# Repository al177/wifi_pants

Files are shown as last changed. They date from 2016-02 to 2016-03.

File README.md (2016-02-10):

# wifi_pants
The dawn of the IoP era

Released under the [Creative Commons Share Alike (CC-BY-SA) License](https://creativecommons.org/licenses/by-sa/4.0/).  Share it, change it, make money on it, teach it to the children as a cautionary tale.  Just make your changes public and give credit to all contributors to this project.

Attributions:

Andrew Litt (dev)

Jerry Dunmire (for the esp8266 Kicad library https://github.com/jdunmire/kicad-ESP8266)

Mike Cousins (for the nice mcous discrete footprints https://github.com/mcous/kicad-lib)

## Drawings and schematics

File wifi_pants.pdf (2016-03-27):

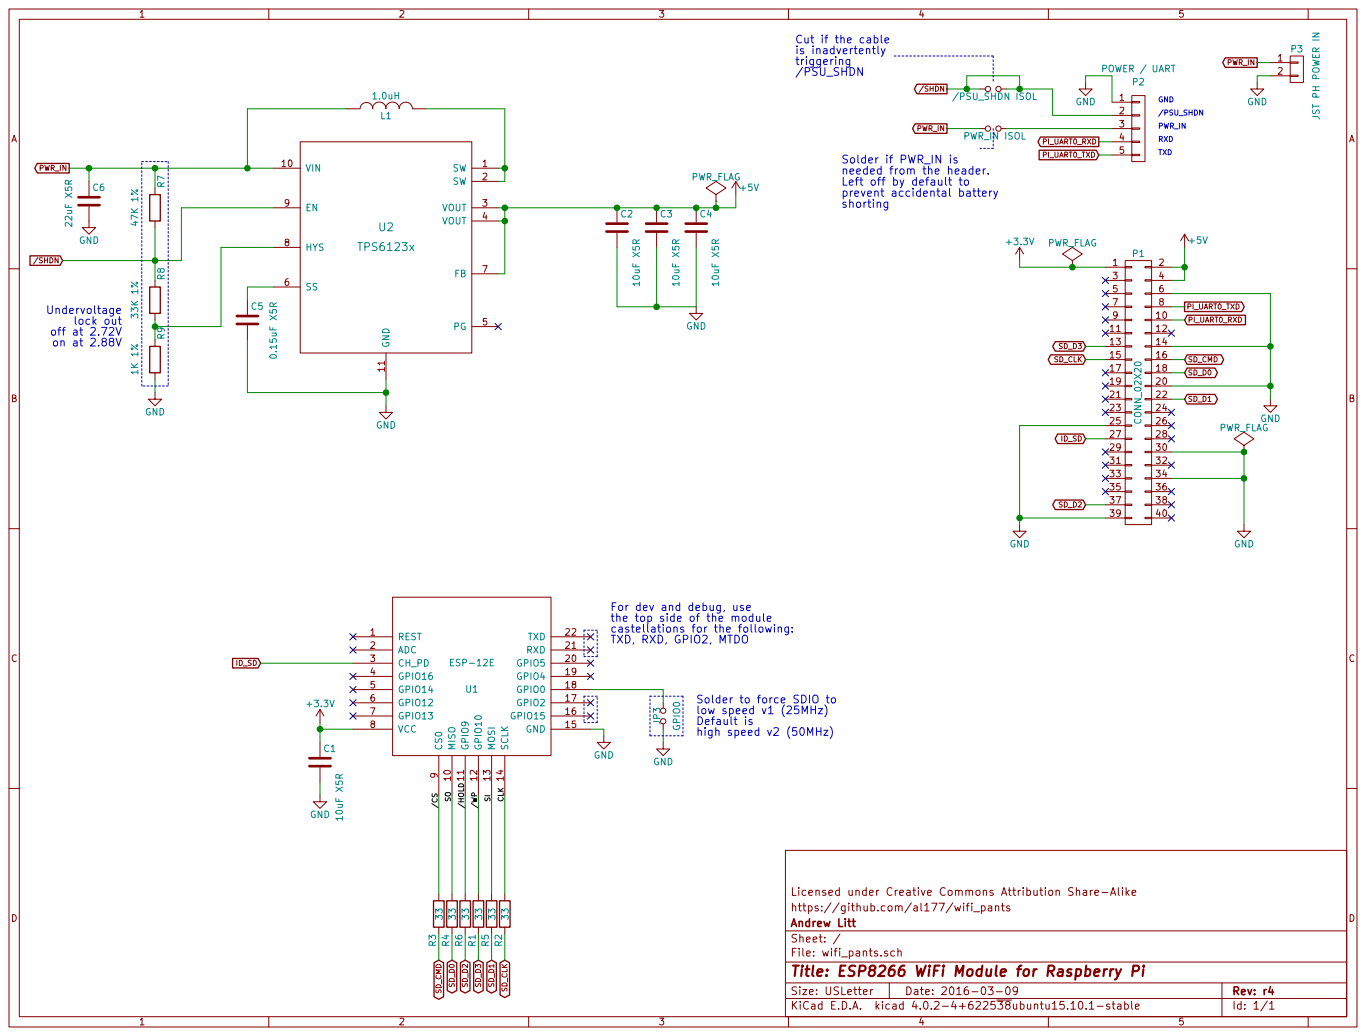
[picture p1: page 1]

/PSU_SHDN ISOL Cut if the cable
is inadvertently
triggering

2 P3 JST PH POWER IN PWR_INGND

RXD For dev and debug, use

GND Undervoltage
lock out off at 2.72V

the top side of the module
castellations for the following:
TXD, RXD, GPIO2, MTDO

9 MISO 10 GPIO5 20 GPIO9 11 RXD 21 GPIO10 12 TXD 22 MOSI 13 SCLK 14 GND 15 GPIO15 16 GPIO2 17 GPIO0 18 GPIO4 19 U1 ESP-12E

Solder to force SDIO to

File: wifi_pants.sch Sheet: / Andrew Litt https://github.com/al177/wifi_pants Licensed under Creative Commons Attribution Share-Alike

Id: 1/1 Title: ESP8266 WiFi Module for Raspberry Pi

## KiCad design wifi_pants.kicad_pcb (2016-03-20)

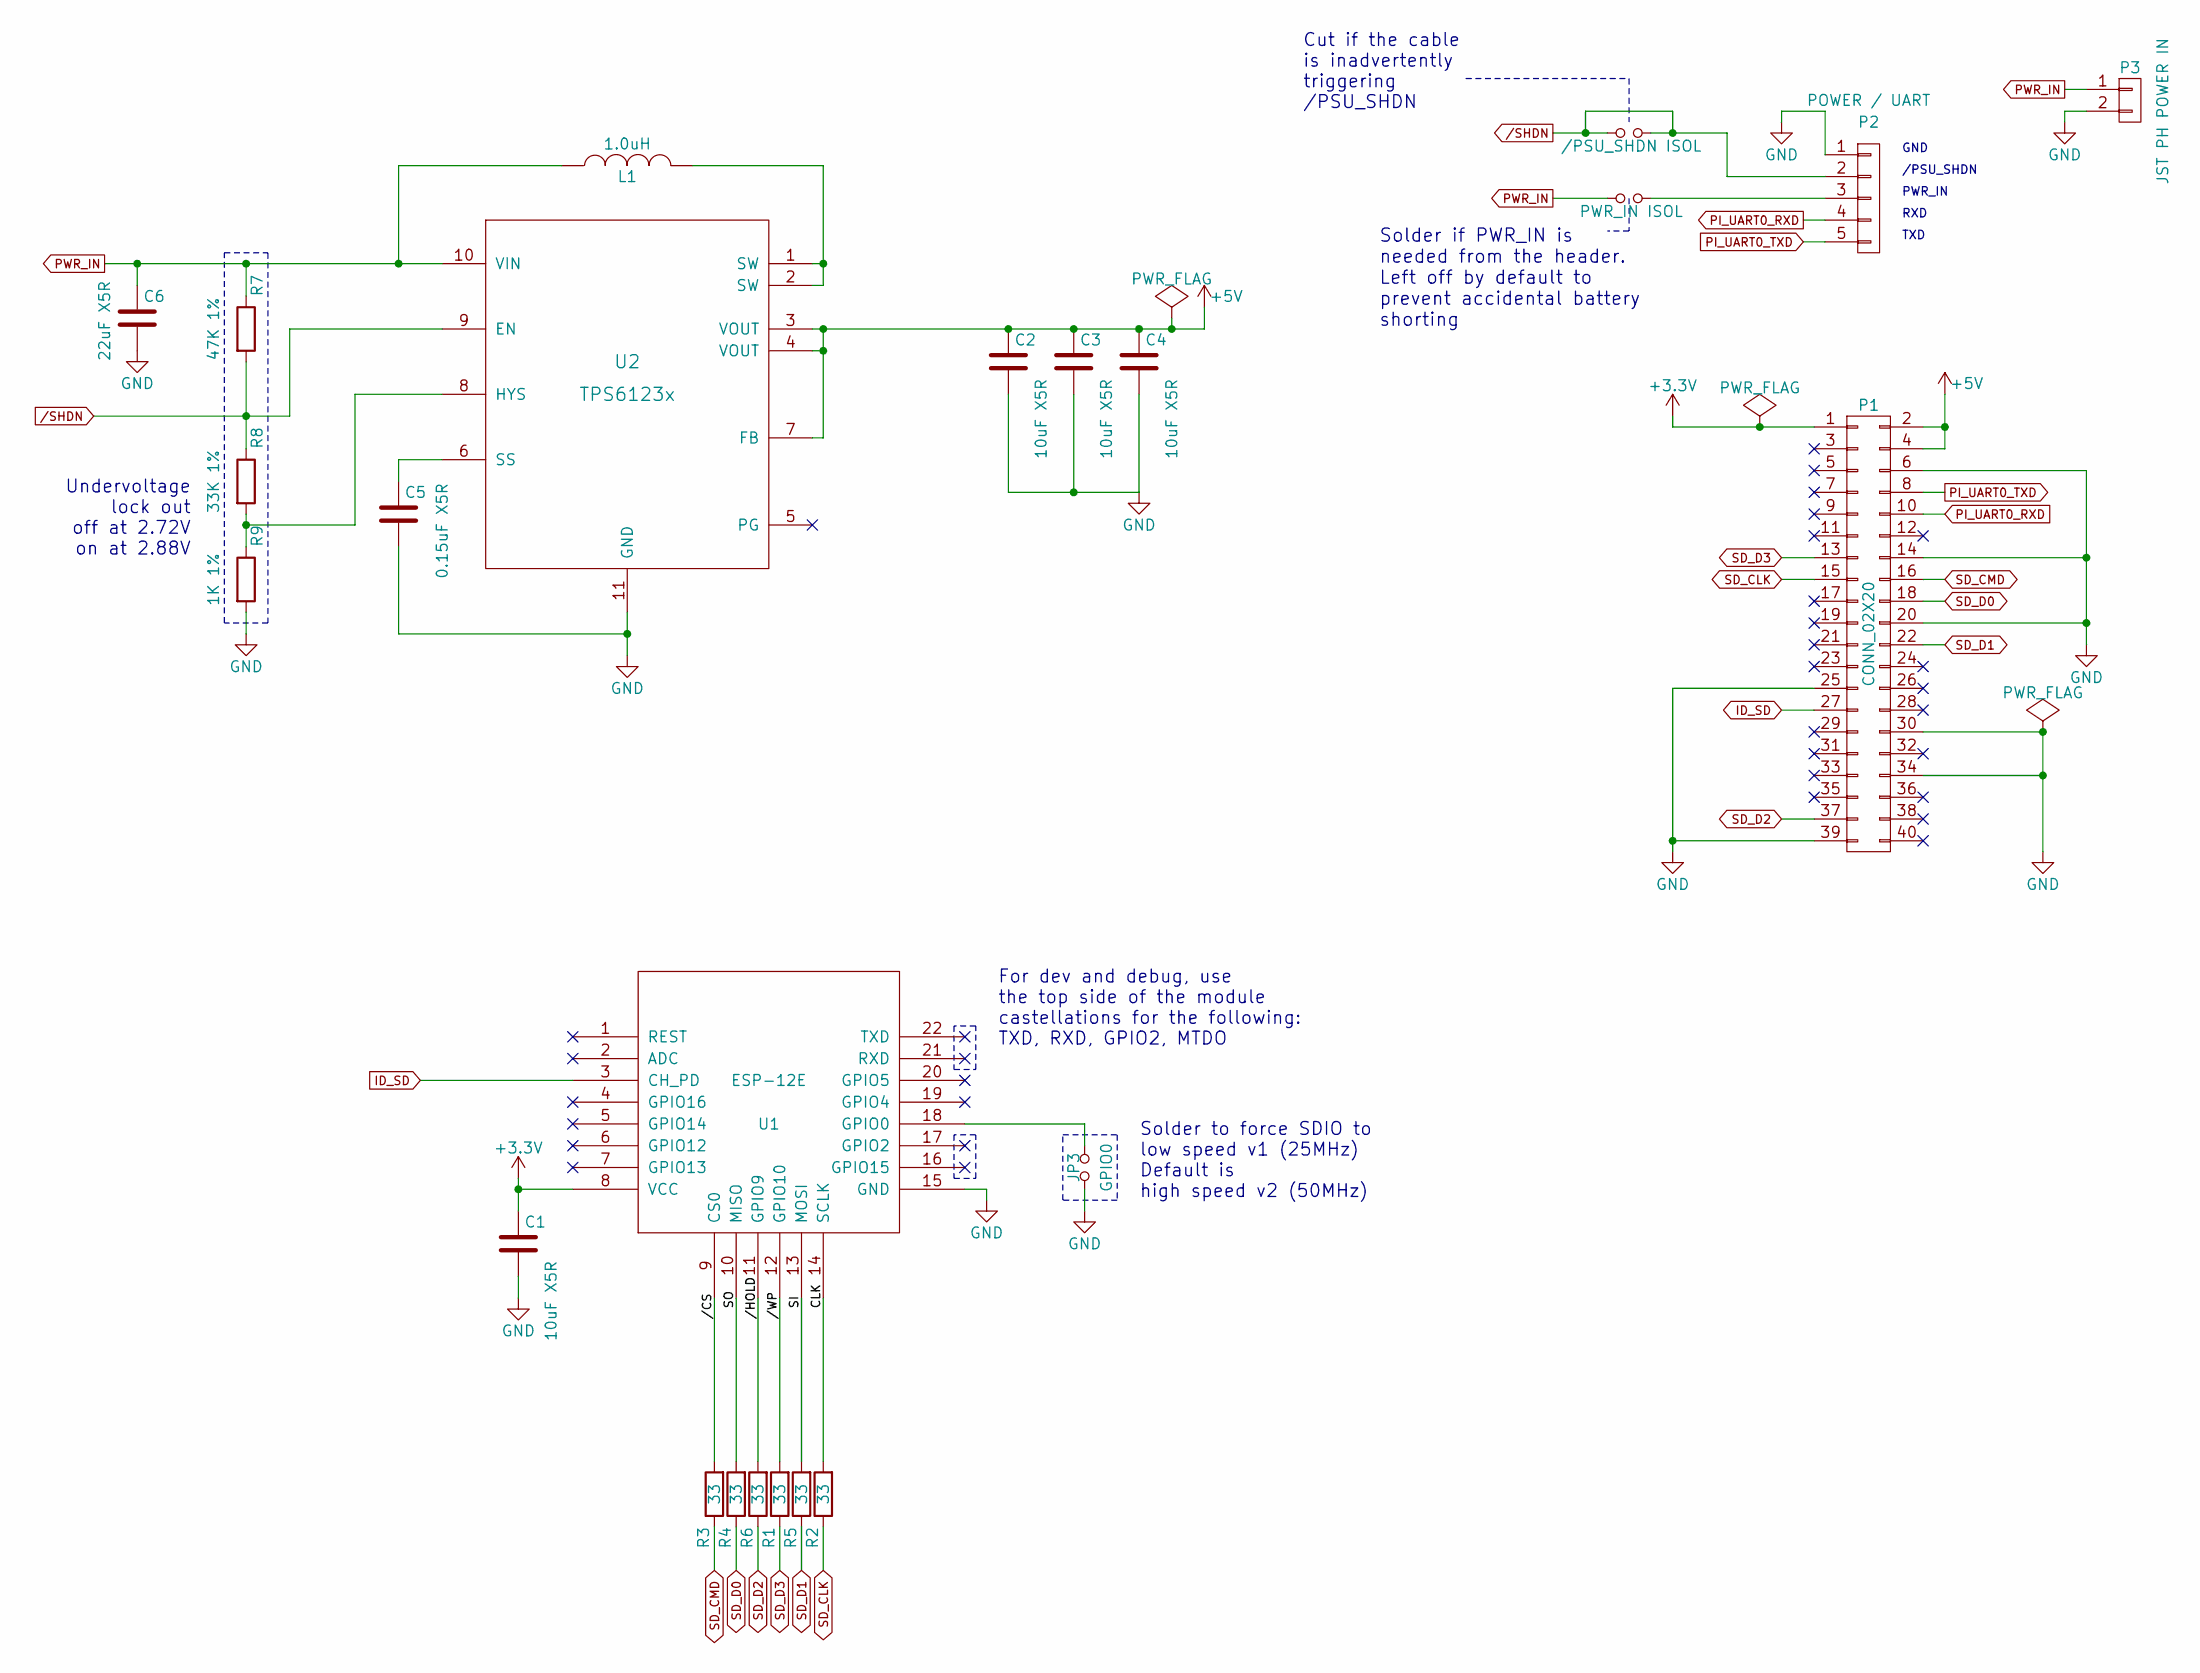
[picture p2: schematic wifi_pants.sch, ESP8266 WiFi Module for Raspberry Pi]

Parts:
C1, C2, C3, C4: 10uF X5R; 0805(2012m)-CHIP-CAP; MFG Part Num LMK212BJ106KG-T; Digikey PN 587-1300-1-ND
C5: 0.15uF X5R; 0603(1608m)-CHIP-CAP; MFG Part Num GRM188R61A154KA01D; Digikey PN 490-11495-1-ND
C6: 22uF X5R; 0805(2012m)-CHIP-CAP; MFG Part Num LMK212BJ226MG-T; Digikey PN 587-1958-1-ND
JP1: /PSU_SHDN ISOL; GS2
JP2: PWR_IN ISOL; GS2
JP3: GPIO0; GS2; MFG Part Num NA
L1: 1.0uH; SRU1028-1R; MFG Part Num SRU1028-1R0Y; Digikey PN SRU1028-1R0YCT-ND
P1: CONN_02X20; Socket_Strip_Straight_2x20_pi; MFG Part Num 2223; Digikey PN 1528-1385-ND
P2: POWER / UART; Pin_Header_Angled_1x05_mirror; MFR Part Num PRPC005SBAN-M71RC; Digikey PN S1111EC-05-ND
P3: JST PH POWER IN; Connectors_JST_S2B-PH-K; MFR Part Num S2B-PH-K-S(LF)(SN); Digikey PN 455-1719-ND
R1, R2, R3, R4, R5, R6: 33; 0603(1608m)-CHIP-RESISTOR; MFG Part Num ERJ-3EKF33R0V; Digikey PN P33.0HCT-ND
R7: 47K 1%; 0603(1608m)-CHIP-RESISTOR; MFG Part Num ERJ-3EKF4702V; Digikey PN P47.0KHCT-ND
R8: 33K 1%; 0603(1608m)-CHIP-RESISTOR; MFG Part Num ERJ-3EKF3302V; Digikey PN P33.0KHCT-ND
R9: 1K 1%; 0603(1608m)-CHIP-RESISTOR; MFG Part Num ERJ-3EKF1001V; Digikey PN P1.00KHCT-ND
U1: ESP-12E; ESP-12E-narrow
U2: TPS6123x; VSON-10; MFR Part Num TPS61232DRC; Digikey PN 296-37990-1-ND

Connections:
+3V3: C1.1, P1.1, U1.8 (VCC)
+5V: C2.1, C3.1, C4.1, P1.2, P1.4, U2.3 (VOUT), U2.4 (VOUT), U2.7 (FB)
//CS: R3.2, U1.9 (CS0)
//HOLD: R6.2, U1.11 (GPIO9)
//WP: R1.2, U1.12 (GPIO10)
/CLK: R2.2, U1.14 (SCLK)
/SHDN: JP1.1, JP1.2, P2.2, R7.2, R8.1, U2.9 (EN)
/SI: R5.2, U1.13 (MOSI)
/SO: R4.2, U1.10 (MISO)
GND: C1.2, C2.2, C3.2, C4.2, C5.2, C6.2, JP3.2, P1.6, P1.14, P1.20, P1.25, P1.30, P1.34, P1.39, P2.1, P3.2, R9.2, U1.15 (GND), U2.11 (GND)
ID_SD: P1.27, U1.3 (CH_PD)
unnamed: C5.1, U2.6 (SS)
unnamed: JP2.2, P2.3
unnamed: JP3.1, U1.18 (GPIO0)
unnamed: L1.2, U2.1 (SW), U2.2 (SW)
unnamed: R8.2, R9.1, U2.8 (HYS)
PI_UART0_RXD: P1.10, P2.4
PI_UART0_TXD: P1.8, P2.5
PWR_IN: C6.1, JP2.1, L1.1, P3.1, R7.1, U2.10 (VIN)
SD_CLK: P1.15, R2.1
SD_CMD: P1.16, R3.1
SD_D0: P1.18, R4.1
SD_D1: P1.22, R5.1
SD_D2: P1.37, R6.1
SD_D3: P1.13, R1.1

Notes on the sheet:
GND
TXD
RXD
For dev and debug, use the top side of the module castellations for the following: TXD, RXD, GPIO2, MTDO
Solder to force SDIO to low speed v1 (25MHz) Default is high speed v2 (50MHz)
/PSU_SHDN
PWR_IN
Cut if the cable is inadvertently triggering /PSU_SHDN
Undervoltage lock out off at 2.72V on at 2.88V
Solder if PWR_IN is needed from the header. Left off by default to prevent accidental battery shorting

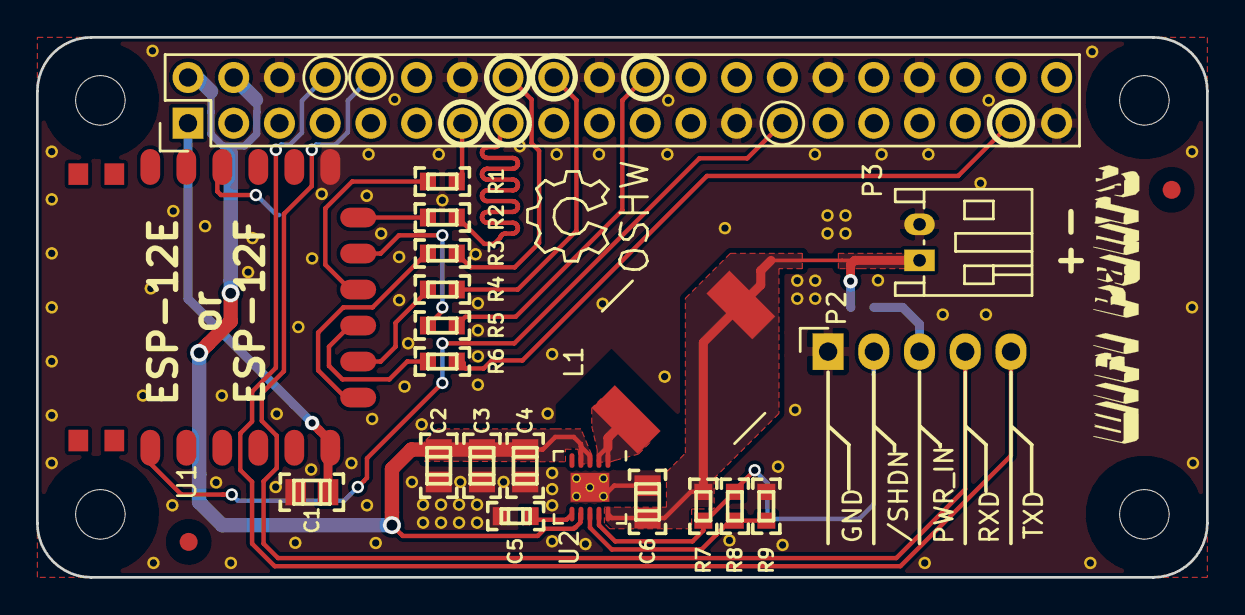
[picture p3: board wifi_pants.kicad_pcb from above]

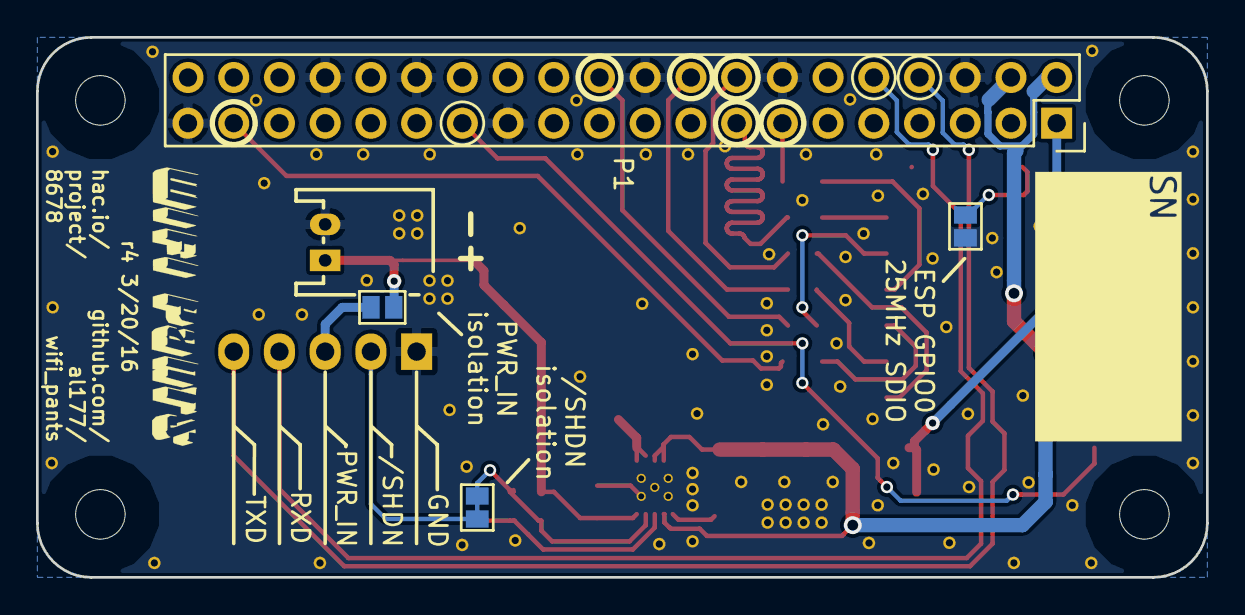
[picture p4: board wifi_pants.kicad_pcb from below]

Board: 2 copper layers, 65.0 x 30.0 mm, 28 parts (4 on the bottom side), 25 nets.

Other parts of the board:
W1, W1#2, W1#3, W1#4: MOUNT; NPTH_Hole_2_75mm

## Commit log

2016-01-15 Add UART header, clean up routing
    [wifi_pants.kicad_pcb, wifi_pants.sch]
2016-01-16 Add audio and expanded header
    [wifi_pants.kicad_pcb, wifi_pants.sch]
2016-01-16 Stitch edge, start cleaning up
    [wifi_pants.kicad_pcb]
2016-01-16 Add audio, change header to include audio and +5V in, cleanup silk
    [wifi_pants.kicad_pcb, wifi_pants.sch]
2016-01-17 Add logo
    [wifi_pants.kicad_pcb]
2016-01-17 Order r1, check in r1 gerbers
    [wifi_pants-B.Cu.gbl, wifi_pants-B.Mask.gbs, wifi_pants-B.SilkS.gbo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]
2016-01-18 Add schematic PDF
2016-01-18 Add 3d views with back mount long pin connector
2016-01-28 r2 schematic and layout
    Changes:
    -move module antenna offboard to clear the Pi board and components
    -SDIO is now routed over a solid ground plane
    -remove test points for UART TX/RX on the module. these can be
    picked off the module topside
    -Default to ID_SD as the CHIP_EN default drive.
    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
    [wifi_pants.kicad_pcb, wifi_pants.sch]
2016-02-10 Remove audio, place connectors, new 4-bit SDIO routing
    [wifi_pants.kicad_pcb, wifi_pants.sch]
2016-02-12 Layout switcher, clean up
    [wifi_pants.kicad_pcb, wifi_pants.sch]
2016-02-13 Changed to a different switcher
    [wifi_pants.kicad_pcb, wifi_pants.sch]
2016-02-13 Clean up PSU layout and silk
    [wifi_pants.kicad_pcb, wifi_pants.sch]
2016-02-14 v3 complete layout
    [wifi_pants-B.Cu.gbl, wifi_pants-B.Mask.gbs, wifi_pants-B.SilkS.gbo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]
2016-02-14 Fab files for v3
    [wifi_pants-B.Cu.gbl, wifi_pants-B.Mask.gbs, wifi_pants-B.SilkS.gbo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]
2016-02-18 Fix some part#s in the schematic, clean up the back side silk for the JST connector
    [wifi_pants-B.Cu.gbl, wifi_pants-B.Mask.gbs, wifi_pants-B.SilkS.gbo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]
2016-03-09 Add UVLO for LiPo, rearrange boost layout, make PWR_IN on header disconnected by default
    [wifi_pants.kicad_pcb, wifi_pants.sch]
2016-03-20 logo and serial number added
    [wifi_pants.kicad_pcb]
2016-03-20 r4 fab files
    [wifi_pants.kicad_pcb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]
2016-03-27 Update PDF schematic to r4
